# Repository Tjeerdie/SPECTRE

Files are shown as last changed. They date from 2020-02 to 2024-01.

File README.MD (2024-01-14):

# Project SPECTRE
Project SPECTRE	(Speeduino PrintEd Circuit board TjeeRdiE). This is a PCB with the hardware to run speeduino on a STM32F407VE6T board from ebay. (Or a STM32 BLACK_F407VE as it is sometimes called). 

Schematics and more information on the cpu board can be found here: (https://github.com/mcauser/BLACK_F407VE)

The case with connectors can be found here: https://nl.aliexpress.com/item/32839361268.html?spm=a2g0z.12010615.8148356.7.1da330edPBhz16

Latest tested version by author is 0.5.3. Version 0.5.4 is a cleaned up schematic plus a change to use resistor arrays rather than individual resistors by @vitorboss. The 0.5.4 version is not build and tested but functionally identical to 0.5.3. 

The design is provided as is. Just as it is stated in the license. The design is a hobby project and not specificly designed to adhere to any standard, so use it at your own risk.

A stand alone Peak and Hold injector driver board is now in a seperate repository. See: https://github.com/Tjeerdie/Peak-And-hold-Driver

## Getting Started
Take a look at the very informative manual for speeduino:
https://speeduino.com/Speeduino_manual.pdf

There is a difference for the TPS with respect to the manual. The TPS must be fed by 3.3V and not 5V like the other speeduino boards. For best performance it is better to wire all the grounds of the sensors to the GND pins and not use the PWR_GND or carchassis for this. 

How to load the firmware to the STM32 see:
https://speeduino.com/forum/viewtopic.php?f=13&t=1914&p=26572#p26572

## Board pinout

The TS Mapping column is the pin you enter in the "Local Auxillary Input Channel Configuration" when repurposing the input pins for another purpose (example: oil pressure sensor):
https://speeduino.com/forum/viewtopic.php?f=14&t=2809

| Pin# | Function | Alternative | Switch | Tuner Studio Mapping |
|-----|---|---|---|---|
| 1 | GND_PWR | | | |
| 2 | GND_PWR | | | |
| 3 | 12V_ECU | | | |
| 4 | 12V_ECU | | | |
| 5 | INJ_CH8 | | | 66 |
| 6 | INJ_CH7 | | | 67 |
| 7 | INJ_CH5 | | | 62 |
| 8 | INJ_CH6 | | | 64 |
| 9 | IDLE1-OUT | STEP_1A_OUT | JP5 | |
| 10  | BARO | | | A13 |
| 11  | Spare_2_out | Step_2B_OUT | JP6 | 71 |
| 12  | Spare_1_Out | Step_1B_OUT | JP7 | 72 |
| 13  | IGN_CH1 | | | |
| 14  | 02_2 | | | A4 |
| 15  | FAN | | | |
| 16  | IDLE2-OUT | STEP_2A_OUT | JP8 | |
| 17  | IAT | | | |
| 18  | IAT_2 | | | A0 |
| 19  | FUEL_PUMP | | | |
| 20  | CLT_2 | | | A1 |
| 21  | RS232_TX | | | |
| 22  | GND | IGN5-OUT | JP18 | |
| 23  | O2 | | | |
| 24  | INJ_CH4 | | | |
| 25  | MAP | | | |
| 26  | GND | IGN6-OUT | JP16 | |
| 27  | CLT | | | |
| 28  | INJ_CH3 | | | |
| 29  | CANH | | | |
| 30  | GND | | | |
| 31  | IGN_CH2 | | | |
| 32  | INJ_CH1 | | | |
| 33  | GND | | | |
| 34  | RS232_RX | | | |
| 35  | TPS | | | |
| 36  | IGN_CH3 | | |  24 |
| 37  | 5V | | | |
| 38  | FLEX_IN | | | |
| 39  | VR2- | | | |
| 40  | IGN_CH4 | | |  34 |
| 41  | VR2+ | | | |
| 42  | VR1- | | | |
| 43  | VR1+ | | | |
| 44  | INJ_CH2 | | | |
| 45  | CANL | | | |
| 46  | 3.3V | | | |
| 47  | BOOST-OUT | | | |
| 48  | TACHO-OUT | | | |

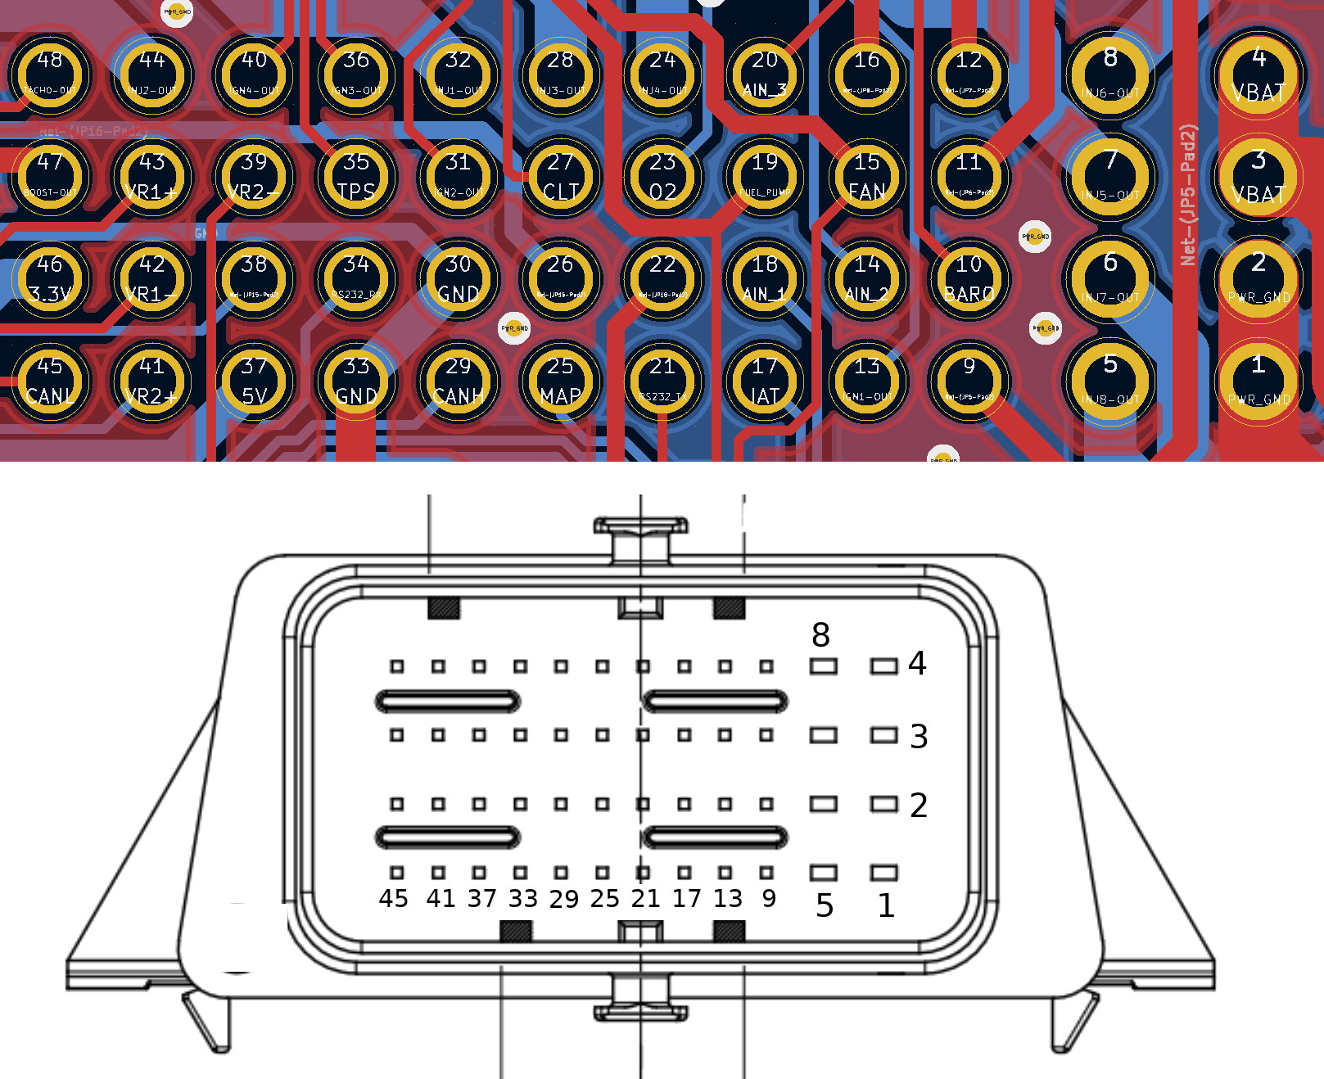
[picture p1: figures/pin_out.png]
connector pinout


## Jumper settings
There are 12 jumpers on the board to set/change various hardware configurations to suit your needs. with a sharp object scratch away the default bridge and use a solder bridge between the alternative configuration pins. The pull up resitors (JP1/JP4) are briged vs non bridged and no need to skratch anything away.
| JP# | Function | Default | Alternative|
|-----|---|---|---|
| 1 | Halleffect Pullup resistor| Not Conneced  | Connected  |
| 2 | Halleffect or VR input VR1| VR | Hall |
| 3 | Halleffect or VR input VR2| Hall | VR |
| 4 | Halleffect Pullup resistor| Not Conneced  | Connected  |
| 5 | STEP_1A_out or IDLE1-OUT  | IDLE1-OUT | STEP_1A_OUT|
| 6 | Spare_2_out or Step_2B_OUT| Spare_2_out | Step_2B_OUT|
| 7 | Spare_1_Out or Step_1B_OUT| Spare_1_Out | Step_1B_OUT|
| 8 | IDLE2-OUT or STEP_2A_OUT  | IDLE2-OUT | STEP_2A_OUT|
| 9  | Tacho out voltage		  | 12V output | 5V output |
| 10  | Ignition trigger out voltage		  | 5V output | 12V output |
| 15  | Flex fuel or Boot0 in | Flexfuel | Boot0 |
| 16  | Ignition 6 or GND | GND | IGN6 |
| 18  | Ignition 5 or GND _ | GND | IGN5 |

## Information for assembling a V0.5.X board
Information for board assembly and choosing components. If  you plan to build one of these it is important to note that a little electronic knowledge is very helpful if not essential to get the board working. The accompanying JLC bom list has most passive components in it, but not all components, some self assembly/soldering and part selection is required.  

### RS232 and bluetooth
The hardware serial port 1 is shared between bluetooth and RS232 output on the ECU connector. So that means you can only build it with the bluetooth module in place OR the max232 ic in place not both! That will break the communication. 

Dont forget to configure the bluetooth module to use 115200 bps baudrate using the HC-05/HC-06 AT commands. 

If you want your main/Tuner studio communiation to use the hardware serial port 1 (So bluetooth or RS232 on the ECU connector). Build the speeduino firmware in the arduino IDE with no "usb support" -> "None". In that case it will default to use hardware serial 1 as the communication.

If the bluetooth comms are not working and you are using a HC-05 or HC-06 module (both are 3.3v so its safe to direcly connect to the MCU). For V0.5.2 of SPECTRE [R37,R38] can be replaced by 0 ohms. For V0.5.3 [R38] can be replaced by 0 ohm. 

### Zener diodes
If you build the board with the injector driver mosfets to be BSP78 [Q10,Q11,Q13,Q14,Q18,Q19,Q20,Q21] you can leave the bzx84C39 + 1N4148 out [33,D34,D35,D36,D37,D38,D39,D40,D41,D42,D43,D44,D45,D46,D47,D48]. These are used for clamping, but the BSP78 has internal clamping. You can use other mosfets with SOT223 footprint in place of the BSP78. If these are not clamped or reptetative avalanch rated use the clamping diodes to keep them in spec.

### Vehicle Speed input
Note: This workaroud is no longer working. There is no solution yet.

Here is a description how to use one of the analog spare inputs (IAT_2 = ECU pin 18) as VSS input for speeduino. This can be a hall type sensor or a porximity sesnsor. it can NOT be a VR type sensor
1. Remove C2 and C4 from the board
2. On the MCU pin headers of the board connect PA0 to PA2 with a bit of solder
3. in Tuner Studio select pin 50 (PA2) for the VSS input pin.

PA0 (pin 48 in TS) can not work as VSS pin because of conflicting interrupts with the crank sensor (PE0)

## Tested on V0.5.2/V0.5.3
The following functions have been tested and confirmed to be working on a volvo B230FK redblock engine. This a 4 cylinder engine with small turbo. A VAG wasted spark coil with internal drivers is used as ignition<br/> 

VR2 input (Trigger 2) [OK]<br/> 
Halleffect trigger input (Trigger 1) [OK]<br/>
VR1 input (Trigger 1) [OK] <br/> 
Halleffect trigger input (Trigger 2) [OK]<br/>
Manifold Absolute pressure (MAP) [OK]<br/>
Injector outputs [OK]<br/>
Lambda sensor (O2) [OK]<br/>
Throttle position input [OK]<br/>
Bluetooth module (PA9,PA10) [OK]<br/>
Battery voltage reading [OK]<br/> 
Ignition outputs [OK]<br/> 
Fuel pump relay [OK]<br/>
FAN relay [OK]<br/>
PWM idle output [OK]<br/>
Coolant temperature (CLT) [OK]<br/>
Inlet Air Temperature (IAT) [OK]<br/>
RS232 TX [OK]<br/>
RS232 RX [OK]<br/>
BOOST output [OK]<br/>
Stepper idle output [OK]<br/> 
TACHO out [OK]<br/>

## To be tested on V0.5.2/V0.5.3
BARO <br/>
CAN bus TX<br/>
CAN bus RX<br/>
FLEX fuel input<br/>
Coolant temperature (CLT_2) <br/>
Inlet Air Temperature (IAT_2) <br/>
Lambda sensor (O2_2) <br/>

## License
This project is licensed under the GNU GENERAL PUBLIC LICENSE - see the [LICENSE.md](LICENSE.md) file for details

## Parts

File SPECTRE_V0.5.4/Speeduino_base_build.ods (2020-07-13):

Id | Designator | Package | Quantity | Designation | Supplier and ref
1 |  | R0603 | 26 | 10k | done for now
2 |  | R0603 | 22 | 1k | done for now
4 | R92,R91,R77,R76,R31 | R0603 | 5 | 1k8 | done for now
5 | R30 | R0603 | 5 | 2k49 | done for now
6 |  | R0603 | 1 | 0R0 | done for now
7 | U2 | TO-220-3_Vertical | 1 | LM78M05_TO220 | done for now
8 | D8 | D_MiniMELF_Handsoldering | 1 | Zener 5.1V | done for now
9 | D33,D32,D28,D27 | D_SMA | 10 | 1N4007 | done for now
11 | U6 | SOIC-16_4.55x10.3mm_P1.27mm | 1 | MAX3232 | done for now
12 | U5 | SO-8_5.3x6.2mm_P1.27mm | 1 | TJA1050
13 | U$1 | WIRELESS-BLUETOOTH-HC-05 | 1 | WIRELESS-BLUETOOTH-HC-05
14 | R97,R96,R79,R78 | R0603 | 15 | 470R | done for now
15 | U3 | SOT-23 | 1 | TL431DBZ | done for now
16 |  | R0603 | 1 | 120R | done for now
18 | Q26,Q25,Q13,Q12 | SOT223 | 11 | BSP78 | done for now
19 | Q22,Q21,Q10,Q11 | SOT-23_Handsoldering | 4 | AO3401A | done for now
20 | Q17,Q16,Q9,Q8 | SOT-23_Handsoldering | 4 | AO3422 | done for now
21 | J2 | PinHeader_2x04_P2.54mm_Vertical | 1 | Conn_02x04_Odd_Even
22 | F2 | R_1812_4532Metric_Pad1.30x3.40mm_HandSolder | 2 | PPTC 16V2A | done for now
23 | J1 | PinHeader_1x06_P2.54mm_Vertical | 1 | Conn_01x06_Male | done for now
24 | U4 | Molex_48 | 1 | molex_48pin | done for now
25 | JP12,JP9 | 2X24 | 2 | PINHD-2X24 | done for now
26 |  | C0603 | 14 | 100nf | done for now
27 |  | C0603 | 12 | 220nf | done for now
28 |  | C0603 | 2 | 1nf | done for now
29 |  | SOT23 | 16 | BAT54S | done for now
30 |  | D_MiniMELF_Handsoldering | 1 | Zener 3.6V | done for now
31 | U1 | 21-0055H_16 | 1 | MAX9926UAEE+
32 | A1 | Pololu_Breakout-16_15.2x20.3mm | 1 | Pololu_Breakout_DRV8825
33 |  | R0603 | 10 | 100R | done for now
34 | R2 | RV_Disc_D12mm_W3.9mm_P7.5mm | 1 | VARISTOR-18V | done for now
35 | R72 | R0603 | 1 | 5470R | done for now
36 | R71 | R0603 | 1 | 100R | done for now
37 | R70 | R0603 | 1 | 220R | done for now
38 |  | LED-0603 | 5 | YEL | done for now
39 | JP11,JP10 | PinHeader_1x02_P2.54mm_Vertical | 2 | Jumper_NO_Small | done for now
40 |  | R0603 | 1 | 5k1 | done for now
41 |  | R0603 | 1 | 33k | done for now
43 |  | R0603 | 4 | 4k7 | done for now
44 |  | R0603 | 4 | 9k1 | done for now
45 | JP4,JP1 | SolderJumper-2_P1.3mm_Open_Pad1.0x1.5mm | 2 | Jumper_NO_Small | done for now
47 |  | C1206 | 2 | 10uf | done for now
48 | Q2,Q5, | SOT-23 | 7 | AO3400

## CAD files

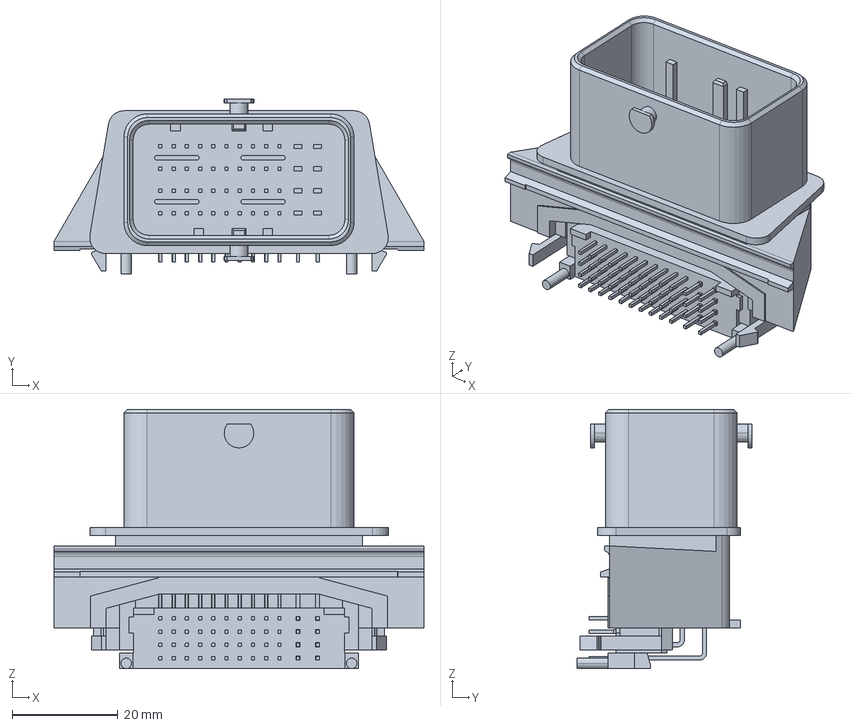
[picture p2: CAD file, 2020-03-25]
SPECTRE_V0.5.4/5007620481.stp
69.9 x 33.2 x 49.0 mm

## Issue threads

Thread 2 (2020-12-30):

BOM file is not complete

pkagiantas, 2020-12-30:
some of the parts have no designation like like the 26 10K resistors etc

Tjeerdie, 2020-12-30:
Ah thanks! fixed it. I used it myself to build the board en removed all numbers already placed on the board. Now i repopulated it again with the latest full BOM.

pkagiantas, 2020-12-30:
cool i ended up finding everything from the eeschema some parts are wrong labeled from the v5.2 schematics

Tjeerdie, 2020-12-30:
you can easily export the same style BOM from kicad. No need to find them by hand!

pkagiantas, 2020-12-30:
thanks ill give it a go

one more question i did got some v5 by mistake do those work ok should i make them or not bother with them ?

Tjeerdie, 2020-12-30:
I have 3 V0.5.2 bare/unpopulated boards here still. I had my engine running on a V0.5.1 and there is another 6 cylinder engine out there that runs an adapted V0.5.1. But i would start with the V0.5.2 that one is the latest the other designs are just put online for reference.

pkagiantas, 2020-12-30:
yeah i received them today 5 of the v5.2 and 5 of the v5 ( by mistake ) i started on V5.2 to test on a bike engine but i was asking if i should keep the v5 or throw them away

Tjeerdie, 2020-12-30:
ah now i understand. The V0.5.0 should work i think... I see some resistor values need tweaking to the new value (like for crank and cam). But in general it could work. but no guarantee.

pkagiantas, 2020-12-30:
cool no wories ! more project to fiddle with ;P

Closed 2020-12-30.

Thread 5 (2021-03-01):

Q12/Q6 Function ?

pkagiantas, 2021-03-01:
hey hi im making my second one 5.2 !

what are the Q12 and Q6 for ? ( PA6 PE6 )

im making it for a 4 cyl wasted spark batch fire engine so im populating just the circuits i need only

Tjeerdie, 2021-03-01:
Q12 is visual feedback that the board is running (PA6 is same pin as the onboard led) so not strictly necessary
Q6 is for the cooling FAN relay. If you want the radiator cooling fan controlled from the speeduino

pkagiantas, 2021-03-01:
cool so board will run with both of those circuits unpopulated correct ?

also i haven't seen a clutch input have you made it or i am just that blind ? :P

Tjeerdie, 2021-03-02:
You would loose aforementioned functionality, nothing else. You could use one of the unused inputs (analog) for clutch.

pkagiantas, 2021-03-02:
so for the clutch do i need to use a darlington array like the 0.4.3 boards or the bard can handle it
and witch pins are unused and analog on the stm ?

sorry for so many questions but i haven't use that board at all

Tjeerdie, 2021-03-03:
For example use AIN_3 for this, if the board is build correctly it should be 15 Volt safe. (never tested so on your own risk). The best way is to remove R57, Make R61 1k. But that is not strictly necessary.  Make sure the bat53s is in place!
ECU pin 20 as input
MCU input PA1 that has number 49 (so use 49 in Tuner Studio).

pkagiantas, 2021-03-03:
thanks im gonna try your way :) 👍

Closed 2021-03-10.

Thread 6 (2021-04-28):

Sd datalog

pkagiantas, 2021-04-28:
im facing a strange issue with the sd card datalog
and i cant seem to make it work

some times it starts logging fine and others i get the sd er and it wont work

have you faced the same issue before ? do you need any more info or tests ?

Tjeerdie, 2021-04-28:
Ah sdcard logging is not SPECTRE specifically ;-). Couple of questions:
- Is the sdcard formatted FAT16 or FAT32?
- Is a file created on the sdcard or no file is created at all?
- Do not install de STM32SD library, that one does that type of errors and more. The corrected library is included in the PR.

pkagiantas, 2021-04-28:
i have to check on the library i cant remember which one i have
the card is fat32 the file is there some times 0kb size tho

pkagiantas, 2021-04-28:
STM32RTC is the library  i use

Tjeerdie, 2021-04-28:
> STM32RTC is the library i use

That's correct. Did you set the RTC time correct? And is the file created with correct time and date?

pkagiantas, 2021-04-28:
yeah files are created with the correct time stamp as a name
it inconsistent when it will work or not
for example today i started the bike 10 times and i got 5-6 files with partial logs some times it runs ok sometimes it starts logging and then stops and sometime it will start with the sd er from the getgo

Tjeerdie, 2021-04-28:
Hmm i had similar issues when i started the Sdcard project. Issues where related to other interrupts running and interrupting Sdcard writes. That stopped the logging at random. But that shouldn't be the case anymore.

I assume you tried various sd-cards? I never had a issue with any. When i have time next week ok so i wil try a fresh install and see if it happens to me too.

pkagiantas, 2021-04-28:
yeah i have tried three sd cards two are the same brand 8gb and one is a 64g that is not working at all :P

Tjeerdie, 2021-04-28:
Welll I updated that without checking with a longer log if Sdcard logging still works as expected. Short still worked. If you open a version of couple of weeks back without newest master merged in maybe it changes something. But should still just work. I will try next week when i hopefully have some time.

pkagiantas, 2021-04-28:
no worries ill try to find an older version to test :D

Closed 2022-07-11.

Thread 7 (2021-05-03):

[Question] Regarding the PPTC fuses

Griletos, 2021-05-03:
I'm having a hard time finding PPTC's with the same 16v2a ratings the project requires here in my country.
Closest ones I was able to find are 16v1.5a and 30v2.5a.
Just wanted to know if one of those are suitable, or if I can use standard 2a fuses, or should I really stick to the 16v2a PPTC, in which case I'll import a few.

Tjeerdie, 2021-05-03:
the 1.5A would be fine. The 2A is just what i had lying around here.
1. The 5 volt regulator only takes maximum 1A continuous so a 1A fuse would be more than enough. 1A is not even possible without cooling the regulator.
2. The stepper driver should also not be much more than 1A continuous but i never tested.

Griletos, 2021-05-03:
Thank you very much, I don't plan on using the stepper driver, so it won't actually pose a problem.

Closed 2021-05-03.

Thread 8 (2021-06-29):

Eagle PCB

TadyTheFish, 2021-06-29:
Could you provide sch and brd files for Eagle PCB?
Thank you

Tjeerdie, 2021-06-30:
Its designed the board using Kicad so i do not have a eagle project anymore.

TadyTheFish, 2021-06-30:
Ok thank you

Closed 2021-06-30.

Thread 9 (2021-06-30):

Clutch switch input

andredalmolin, 2021-06-30:
Hi!
I'm just finishing the wiring for an Spectre to use in an VW Jetta 2.5 5cyl with turbo.
We wish to use flat shift, but I didnt find an clutch input. There is any unused input that I can reassign to clutch input?

Tjeerdie, 2023-07-02:
Sorry for the late response, but maybe someone else can still sue this

You could try use the flex fuel input pin, if you do not have a flex fuel sensor connected

Closed 2023-07-02.

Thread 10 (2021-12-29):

Some info is not correct

pkagiantas, 2021-12-29:
Baro is working when set to pin Α13 on Tuner Studio not on A9

JP15 ( Flex fuel or Boot0 ) does not existing in V5.2

Halleffect or VR input VR1 default on V5.2 is on HALL not on VR

on the Jumper section you have (  Ignition 6 or GND ) for the IGN7

thats what i have found so far it might help someone
your master is working fine on my engine ( kawasaki z1000 )
( cant get a good cam signal to run sequential but i think that is not related to the board )

the only thinks missing is the datalogging on the sd ( its a must for a bike if you want to road tune it )
quick shifter would be nice too but cant get it all :P

also what is the latest board version 5.2 or 5.3 or 5.4 ?

Tjeerdie, 2023-07-02:
Thanks! I checked all of them and changed most of them in the readme

Except the VR1 being default to VR, because that is actually the case. (I use the VR sensor and the jumper is in the default setting)

Closed 2023-07-02.

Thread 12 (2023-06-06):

Can I Use A Diffrent Stepper Driver?

CaptionAdam, 2023-06-06:
Title Explains it quite nicely

Tjeerdie, 2023-07-02:
If its pin compatible with the current stepper drive i would´t see why not.

These are a few different boards with the same pinout.

google for:
A4988 Stepper Motor Driver Carrier Board alternatives

Closed 2023-07-02.

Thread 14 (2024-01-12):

Partly assembled PCB

anyoneeee, 2024-01-12:
Hi, I´m not really into electronics, but I gave it a try and ordered some PCB from PCBWay. They partly assembled the board. Now I see that all the mosfets weren´t in the BOM I found (it´s V0.5.3 btw). At Q10 is not very much space to D37. Do I need D37? What is D37? Where do I find a complete BOM? Do you have pictures of your board? I can´t find any pictures from people that have built the board. So many questions...
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

Tjeerdie, 2024-01-14:
Hi anyoneeee

First of all i will add to the read-me that it might be a good idea to be familiar with electronics before building this board. It all works if build with according to the schematics. But you might need to fiddle a bit to get some things working. For your specific application.  Also soldering parts yourself is required.

I will add to the read-me that the jlc-pcb bom list is not complete, mostly because they do not have all the parts in their inventory.  And also assembly on the bottom side is not supported by JLC pcb. And no thu-hole components are assembled by JLC. I am actually surprised the BOM list still worked! Because usually parts are added/removed from the inventory list on a regular basis. The full BOM list could easily be generated from Kicad using the schematic

The BSP78 I used is also hard to come by now days. So a IRFL024N is a non protected mosfet that i used as a alternative. But it has no protection so it is easier to blow one up when somethings are connected wrong.

I will add some pictures of one of my boards assembled to the point that I could use it.

anyoneeee, 2024-01-14:
Hi Tjeerdie, thank you for the quick answer. Knowing how to use KiCad a little bit helps too and reading the description also 😄 . I ordered the BSP78, very cool MOSFET. I didn´t know they could have a short circuit protection in that little thing. Pictures of your assembled boards would be very helpful for me. Did you already use the board on other engines than the 4 cylinder in the description? Thank you for your support.

From your description:
Zener diodes
If you build the board with the injector driver mosfets to be BSP78 [Q10,Q11,Q13,Q14,Q18,Q19,Q20,Q21] you can leave the bzx84C39 + 1N4148 out [33,D34,D35,D36,D37,D38,D39,D40,D41,D42,D43,D44,D45,D46,D47,D48]. These are used for clamping, but the BSP78 has internal clamping. You can use other mosfets with SOT223 footprint in place of the BSP78. If these are not clamped or reptetative avalanch rated use the clamping diodes to keep them in spec.

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

#,"Reference","Qty","Value","Footprint","DNP"
--
1,"A1","1","Pololu_Breakout_DRV8825","Module:Pololu_Breakout-16_15.2x20.3mm",""
2,"C1, C2, C9, C10, C13, C19, C21,   C22, C25, C26, C29, C30, C31,   C32","14","100nf","Speeduino_base:C0603",""
3,"C3, C4, C8, C11, C14, C16, C17,   C20, C23, C24, C27,   C28","12","220nf","Speeduino_base:C0603",""
4,"C5,   C7","2","1nf","Speeduino_base:C0603",""
5,"C6,   C15","2","10uf","Speeduino_base:C1206",""
6,"C12,   C18","2","470uF   6.3V","Capacitor_SMD:CP_Elec_6.3x7.7",""
7,"D1, D2, D3, D5, D7, D9, D10, D11,   D12, D15, D16, D17, D19, D21, D22,   D24","16","BAT54S","Speeduino_base:SOT23",""
8,"D4, D14, D20, D30, D31,   D32","6","1N4007","Diode_SMD:D_SMA",""
9,"D6","1","Zener   3.6V","Diode_SMD:D_MiniMELF_Handsoldering",""
10,"D8","1","Zener   5.1V","Diode_SMD:D_MiniMELF_Handsoldering",""
11,"D13, D18, D26, D27, D28,   D29","6","YEL","Speeduino_base:LED-0603",""
12,"D33, D35, D36, D39, D40, D43,   D44,   D45","8","1N4148WS","Diode_SMD:D_SOD-323",""
13,"D34, D37, D38, D41, D42, D46,   D47,   D48","8","BZX84C39","Diode_SMD:D_SOT-23_ANK",""
14,"F1,   F2","2","PPTC   16V2A","Resistor_SMD:R_1812_4532Metric_Pad1.30x3.40mm_HandSolder",""
15,"J1","1","Conn_01x06_Male","Connector_PinHeader_2.54mm:PinHeader_1x06_P2.54mm_Vertical",""
16,"J2","1","Conn_02x04_Odd_Even","Speeduino_base:PinHeader_2x04_P2.54mm_Vertical",""
17,"J3","1","ProtoArea","Speeduino_base:Proto_area",""
18,"JP1,   JP4","2","Jumper_NO_Small","Jumper:SolderJumper-2_P1.3mm_Open_Pad1.0x1.5mm",""
19,"JP2, JP3, JP5, JP6, JP7, JP8,   JP9, JP10, JP15, JP16,   JP18","11","SolderJumper_3_Bridged12","Jumper:SolderJumper-3_P1.3mm_Bridged12_Pad1.0x1.5mm",""
20,"JP11,   JP12","2","PINHD-2X24","Speeduino_base:2X24",""
21,"JP13","1","Jumper_NC_Small","Jumper:SolderJumper-2_P1.3mm_Bridged_Pad1.0x1.5mm",""
22,"JP14","1","Jumper_NO_Small","Connector_PinHeader_2.54mm:PinHeader_1x02_P2.54mm_Vertical",""
23,"Q1, Q6, Q7,   Q12","4","AO3400","Speeduino_base:SOT-23",""
24,"Q10, Q11, Q13, Q14, Q15, Q16,   Q17, Q18, Q19, Q20,   Q21","11","BSP78","Speeduino_base:SOT223",""
25,"R1, R22, R31, R42,   R57","5","2k49","Speeduino_base:R0603",""
26,"R2","1","VARISTOR-18V","Varistor:RV_Disc_D12mm_W3.9mm_P7.5mm",""
27,"R3, R12, R15, R21, R32, R35,   R65, R68,   R69","9","1k","Speeduino_base:R0603",""
28,"R4, R6, R8, R18, R23, R24, R27,   R33, R37, R41, R49, R50, R55, R60, R61, R64,   R77","17","470R","Speeduino_base:R0603",""
29,"R5, R11, R13, R14, R16, R19,   R36, R59, R66, R79, R80, R81, R82, R86, R87, R88, R89, R90, R91,   R92","20","10k","Speeduino_base:R0603",""
30,"R7, R17, R38, R58, R62, R63,   R70,   R71","8","10R","Resistor_SMD:R_0603_1608Metric_Pad1.05x0.95mm_HandSolder",""
31,"R9, R25, R28,   R46","4","4k7","Speeduino_base:R0603",""
32,"R10, R26, R29,   R47","4","9k1","Speeduino_base:R0603",""
33,"R20","1","0R0","Speeduino_base:R0603",""
34,"R30","1","1k8","Speeduino_base:R0603",""
35,"R34, R39, R40, R43, R48, R51,   R52, R53, R54, R56, R67, R76, R78, R83, R84,   R85","16","100R","Speeduino_base:R0603",""
36,"R44","1","33k","Speeduino_base:R0603",""
37,"R45","1","5k1","Speeduino_base:R0603",""
38,"R74","1","120R","Speeduino_base:R0603",""
39,"R75","1","220R","Speeduino_base:R0603",""
40,"U1","1","MAX9926UAEE+","Speeduino_base:21-0055H_16",""
41,"U2","1","LM78M05_TO220","Package_TO_SOT_THT:TO-220-3_Horizontal_TabUp",""
42,"U3","1","TL431DBZ","Package_TO_SOT_SMD:SOT-23",""
43,"U4","1","molex_48pin","Speeduino_base:Molex_48",""
44,"U5","1","TJA1050","Package_SO:SO-8_5.3x6.2mm_P1.27mm",""
45,"U6","1","MAX3232","Package_SO:SOIC-16_4.55x10.3mm_P1.27mm",""
46,"U7, U8, U9,   U10","4","MIC4427","Package_SO:SO-8_3.9x4.9mm_P1.27mm",""
47,"U$1","1","WIRELESS-BLUETOOTH-HC-05","Speeduino_base:WIRELESS-BLUETOOTH-HC-05",""

anyoneeee, 2024-01-19:
Assembled most of the parts today. Only the HC-05 Bluetooth module and the MAX9926UAEE+ VR Sensor Interface are missing.

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

Closed 2024-01-21.

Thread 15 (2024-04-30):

Which branch/fork to use yours or Vitors?

ruckusman, 2024-04-30:
Not really an issue but probably the best way to contact you - I've located Vitor's fork and noticed that he has made some recent commits to his.

https://github.com/VitorBoss/SPECTRE

Would it be preferable to use his fork to get PCB's fabricated?

Awesome board by the way, I don't understand why it hasn't received much more attention - the feature set is excellent or 4 cylider dual injector builds.

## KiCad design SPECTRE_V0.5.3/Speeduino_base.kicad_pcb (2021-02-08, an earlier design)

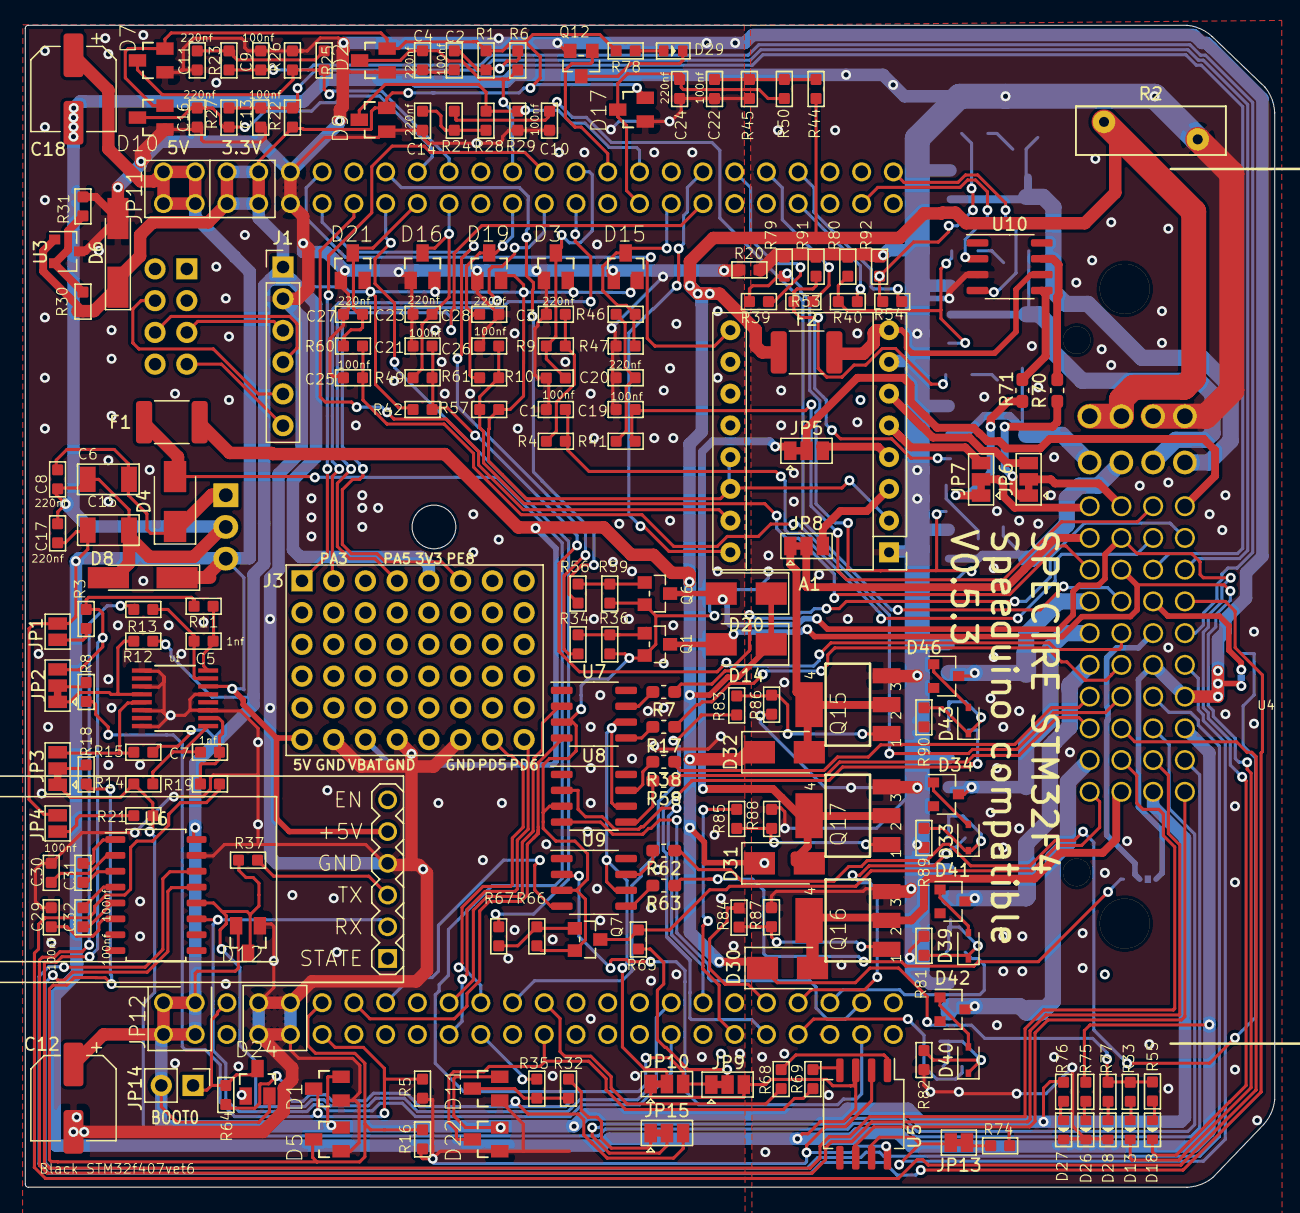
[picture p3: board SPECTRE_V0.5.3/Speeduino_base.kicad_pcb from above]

Board: 2 copper layers, 100.0 x 93.0 mm, 217 parts (0 on the bottom side), 180 nets.

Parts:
A1: Pololu_Breakout_DRV8825; Pololu_Breakout-16_15.2x20.3mm
C1, C2, C9, C10, C13, C19, C21, C22, C25, C26, C29, C30, C31, C32: 100nf; C0603
C3, C4, C8, C11, C14, C16, C17, C20, C23, C24, C27, C28: 220nf; C0603
C5, C7: 1nf; C0603
C6, C15: 10uf; C1206
C12, C18: 470uF 6.3V; CP_Elec_6.3x7.7
D1, D2, D3, D5, D7, D9, D10, D11, D12, D15, D16, D17, D19, D21, D22, D24: BAT54S; SOT23
D4, D14, D20, D30, D31, D32: 1N4007; D_SMA
D6: Zener 3.6V; D_MiniMELF_Handsoldering
D8: Zener 5.1V; D_MiniMELF_Handsoldering
D13, D18, D26, D27, D28, D29: YEL; LED-0603
D33, D35, D36, D39, D40, D43, D44, D45: 1N4148WS; D_SOD-323
D34, D37, D38, D41, D42, D46, D47, D48: BZX84C39; D_SOT-23_ANK
F1, F2: PPTC 16V2A; R_1812_4532Metric_Pad1.30x3.40mm_HandSolder
J1: Conn_01x06_Male; PinHeader_1x06_P2.54mm_Vertical
J2: Conn_02x04_Odd_Even; PinHeader_2x04_P2.54mm_Vertical
J3: ProtoArea; Proto_area
JP1, JP4: Jumper_NO_Small; SolderJumper-2_P1.3mm_Open_Pad1.0x1.5mm
JP2, JP3, JP5, JP6, JP7, JP8, JP9, JP10, JP15, JP16, JP18: SolderJumper_3_Bridged12; SolderJumper-3_P1.3mm_Bridged12_Pad1.0x1.5mm
JP11, JP12: PINHD-2X24; 2X24
JP13: Jumper_NC_Small; SolderJumper-2_P1.3mm_Bridged_Pad1.0x1.5mm
JP14: Jumper_NO_Small; PinHeader_1x02_P2.54mm_Vertical
Q1, Q6, Q7, Q12: AO3400; SOT-23
Q10, Q11, Q13, Q14, Q15, Q16, Q17, Q18, Q19, Q20, Q21: BSP78; SOT223
R1, R22, R31, R42, R57: 2k49; R0603
R2: VARISTOR-18V; RV_Disc_D12mm_W3.9mm_P7.5mm
R3, R12, R15, R21, R32, R35, R65, R68, R69: 1k; R0603
R4, R6, R8, R18, R23, R24, R27, R33, R37, R41, R49, R50, R55, R60, R61, R64, R77: 470R; R0603
R5, R11, R13, R14, R16, R19, R36, R59, R66, R79, R80, R81, R82, R86, R87, R88, R89, R90, R91, R92: 10k; R0603
R7, R17, R38, R58, R62, R63, R70, R71: 10R; R_0603_1608Metric_Pad1.05x0.95mm_HandSolder
R9, R25, R28, R46: 4k7; R0603
R10, R26, R29, R47: 9k1; R0603
R20: 0R0; R0603
R30: 1k8; R0603
R34, R39, R40, R43, R48, R51, R52, R53, R54, R56, R67, R76, R78, R83, R84, R85: 100R; R0603
R44: 33k; R0603
R45: 5k1; R0603
R74: 120R; R0603
R75: 220R; R0603
U1: MAX9926UAEE+; 21-0055H_16
U2: LM78M05_TO220; TO-220-3_Horizontal_TabUp
U3: TL431DBZ; SOT-23
U4: molex_48pin; Molex_48
U5: TJA1050; SO-8_5.3x6.2mm_P1.27mm
U6: MAX3232; SOIC-16_4.55x10.3mm_P1.27mm
U7, U8, U9, U10: MIC4427; SO-8_3.9x4.9mm_P1.27mm
U$1: WIRELESS-BLUETOOTH-HC-05

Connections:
3.3V: A1.2, A1.13, A1.14, C12.1, D1.2, D2.2, D3.2, D5.2, D6.1, D7.2, D9.2, D10.2, D11.2, D12.2, D15.2, D16.2, D17.2, D19.2, D21.2, D22.2, D24.2, J1.1, J3.5, JP11.5, JP11.6, JP11.7, JP11.8, JP12.1, JP12.2, JP12.3, JP12.4, JP14.2, R1.2, R12.2, R15.2, R22.2, R30.1, R42.2, R57.2, R76.2, R78.2, U3.1, U4.46, U6.16
5V: C15.2, C17.2, C18.1, D8.1, J3.41, JP1.2, JP4.2, JP9.3, JP10.1, JP11.1, JP11.2, JP11.3, JP11.4, R75.2, U1.14, U2.3, U4.37, U5.3, U$1.5
/BT_TX: R37.2, U$1.3
AIN_1: C2.2, R1.1, R6.1, U4.18
AIN_2: C1.2, R4.1, U4.14
AIN_3: C26.2, R57.1, R61.1, U4.20
BARO: C19.2, R41.1, U4.10
BME280_CS: J1.5, J2.4
BOOST-OUT: D30.2, Q16.2, Q16.4, U4.47
BOOT0: D24.3, JP12.5, JP14.1, R64.1
BOOT0_EXT: JP15.3, R64.2
CANH: JP13.2, U4.29, U5.7
CANL: R74.2, U4.45, U5.6
CLT: C21.2, R42.1, R49.1, U4.27
FAN: D18.-, D20.2, Q6.3, U4.15
FLEX_FUEL_IN: JP15.1, R32.2
FUEL_PUMP: D13.-, D14.2, Q1.3, U4.19
GND: C1.1, C2.1, C3.1, C4.1, C9.1, C10.1, C11.1, C12.2, C13.1, C14.1, C16.1, C19.1, C20.1, C21.1, C22.1, C23.1, C24.1, C25.1, C26.1, C27.1, C28.1, C29.2, C30.2, D1.1, D2.1, D3.1, D5.1, D6.2, D7.1, D9.1, D10.1, D11.1, D12.1, D15.1, D16.1, D17.1, D19.1, D21.1, D22.1, D24.1, J1.2, J3.42, J3.44, J3.46, JP11.9, JP11.10, JP12.7, JP12.8, JP12.9, JP12.10, JP16.1, JP18.1, Q12.2, R5.2, R10.1, R16.2, R20.1, R26.1, R29.1, R31.2, R45.1, R47.1, U1.1, U1.3, U1.6, U1.8, U1.11, U1.13, U3.3, U4.30, U4.33, U5.2, U5.8, U6.15, U$1.4
IAT: C13.2, R22.1, R27.1, U4.17
IDLE1-OUT: D31.2, JP5.1, Q17.2, Q17.4
IDLE2-OUT: D32.2, JP8.1, Q15.2, Q15.4
IGN1-OUT: R7.1, U4.13
IGN2-OUT: R17.1, U4.31
IGN3-OUT: R38.1, U4.36
IGN4-OUT: R58.1, U4.40
IGN5-OUT: JP18.3, R62.1
IGN6-OUT: JP16.3, R63.1
INJ1-OUT: D41.1, Q13.2, Q13.4, U4.32
INJ2-OUT: D42.1, Q14.2, Q14.4, U4.44
INJ3-OUT: D34.1, Q18.2, Q18.4, U4.28
INJ4-OUT: D46.1, Q19.2, Q19.4, U4.24
INJ5-OUT: D37.1, Q10.2, Q10.4, U4.7
INJ6-OUT: D47.1, Q20.2, Q20.4, U4.8
INJ7-OUT: D38.1, Q11.2, Q11.4, U4.6
INJ8-OUT: D48.1, Q21.2, Q21.4, U4.5
MAP: C9.2, R23.1, U4.25
unnamed: C3.2, R4.2, R9.1
unnamed: C5.1, R13.2, U1.15
unnamed: C5.2, R11.2, U1.16
unnamed: C6.2, C8.2, D4.1, U2.1
unnamed: C7.1, R19.2, U1.10
unnamed: C7.2, R14.2, U1.9
unnamed: C11.2, R23.2, R25.1
unnamed: C14.2, R24.2, R28.1
unnamed: C20.2, R41.2, R46.1
unnamed: C22.2, R44.1, R45.2, R50.1
unnamed: C29.1, U6.6
unnamed: C30.1, U6.2
unnamed: C31.1, U6.1
unnamed: C31.2, U6.3
unnamed: C32.1, U6.4
unnamed: C32.2, U6.5
unnamed: D11.3, R32.1, R35.2
unnamed: D13.+, R33.1
unnamed: D18.+, R55.1
unnamed: D26.+, R75.1
unnamed: D27.+, R76.1
unnamed: D28.+, R77.1
unnamed: D29.+, R78.1
unnamed: D29.-, Q12.3
unnamed: D33.1, Q18.1, R52.1, R89.1
unnamed: D33.2, D34.2
unnamed: D35.1, Q10.1, R39.1, R79.1
unnamed: D35.2, D37.2
unnamed: D36.1, Q11.1, R40.1, R80.1
unnamed: D36.2, D38.2
unnamed: D39.1, Q13.1, R43.1, R81.1
unnamed: D39.2, D41.2
unnamed: D40.1, Q14.1, R48.1, R82.1
unnamed: D40.2, D42.2
unnamed: D43.1, Q19.1, R51.1, R90.1
unnamed: D43.2, D46.2
unnamed: D44.1, Q20.1, R53.1, R91.1
unnamed: D44.2, D47.2
unnamed: D45.1, Q21.1, R54.1, R92.1
unnamed: D45.2, D48.2
unnamed: JP1.1, R3.2
unnamed: JP2.1, R12.1, U1.4
unnamed: JP2.2, R8.2
unnamed: JP3.2, R18.2
unnamed: JP3.3, R15.1, U1.5
unnamed: JP4.1, R21.2
unnamed: JP5.2, U4.9
unnamed: JP6.2, U4.11
unnamed: JP7.2, U4.12
unnamed: JP8.2, U4.16
unnamed: JP9.2, R65.2
unnamed: JP10.2, U7.6, U8.6, U9.6
unnamed: JP13.1, R74.1
unnamed: JP15.2, U4.38
unnamed: JP16.2, U4.26
unnamed: JP18.2, U4.22
unnamed: Q1.1, R34.2, R36.1
unnamed: Q6.1, R56.2, R59.1
unnamed: Q7.1, R66.2, R67.2
unnamed: Q15.1, R83.2, R86.2
unnamed: Q16.1, R84.2, R87.2
unnamed: Q17.1, R85.2, R88.2
unnamed: R7.2, U7.7
unnamed: R17.2, U7.5
unnamed: R30.2, R31.1, U3.2
unnamed: R38.2, U8.7
unnamed: R58.2, U8.5
unnamed: R62.2, U9.7
unnamed: R63.2, U9.5
unnamed: R68.2, U5.1
unnamed: R69.2, U5.4
unnamed: R70.2, U10.7
unnamed: R71.2, U10.5
O2: C10.2, R24.1, U4.23
PA0: C4.2, D2.3, JP11.23, R6.2
PA1: C28.2, D19.3, JP11.24, R61.2
PA2: J3.1, JP11.25
PA3: J3.2, JP11.26
PA4: D3.3, JP11.27, R9.2, R10.2
PA5: J3.4, JP11.28
PA6: JP11.29, Q12.1
PA8: JP12.35, U8.2
PA9: JP12.34, U6.11, U$1.2
PA10: D12.3, JP12.33, R37.1, U6.12
PB1: D15.3, JP11.34, R46.2, R47.2
PB7: JP12.15, U9.4
PB9: JP12.13, U7.4
PB12: JP11.46, U10.2
PB13: JP11.47, U10.4
PC0: C16.2, D10.3, JP11.17, R27.2
PC1: C27.2, D21.3, JP11.18, R60.2
PC2: D7.3, JP11.19, R25.2, R26.2
PC3: C23.2, D16.3, JP11.20, R49.2
PC4: D9.3, JP11.31, R28.2, R29.2
PC5: C24.2, D17.3, JP11.32, R50.2
PC6: JP12.39, R84.1
PC7: JP12.38, R85.1
PC13: JP11.16, R67.1
PD0: D22.3, JP12.26, R69.1
PD1: JP12.25, R68.1
PD3: JP12.23, R83.1
PD4: JP12.22, R35.1
PD5: J3.47, JP12.21
PD6: J3.48, JP12.20
PD7: JP12.19, U7.2
PD9: JP12.46, U9.2
PD10: JP12.45, U8.4
PD12: JP12.43, R43.2
PD13: JP12.42, R48.2
PD14: JP12.41, R52.2
PD15: JP12.40, R51.2
PE0: D1.3, JP12.12, R5.1, R8.1
PE1: D5.3, JP12.11, R16.1, R18.1
PE2: A1.9, JP11.11
PE3: JP11.12, R34.1
PE5: A1.15, JP11.14
PE6: JP11.15, R56.1
PE7: A1.16, JP11.35
PE8: J3.6, JP11.36
PE9: JP11.37, R39.2
PE11: JP11.39, R53.2
PE13: JP11.41, R54.2
PE14: JP11.42, R40.2
PWR_GND: A1.1, A1.7, C6.1, C8.1, C15.1, C17.1, C18.2, D8.2, D26.-, D27.-, D28.-, Q1.2, Q6.2, Q7.2, Q10.3, Q11.3, Q13.3, Q14.3, Q15.3, Q16.3, Q17.3, Q18.3, Q19.3, Q20.3, Q21.3, R2.1, R20.2, R36.2, R59.2, R66.1, R79.2, R80.2, R81.2, R82.2, R86.1, R87.1, R88.1, R89.2, R90.2, R91.2, R92.2, U2.2, U4.1, U4.2, U7.3, U8.3, U9.3, U10.3
RS232_RX: U4.34, U6.13
RS232_TX: U4.21, U6.14
SPI1_MISO: J1.6, J2.7
SPI1_MOSI: J1.4, J2.6
SPI1_SCK: J1.3, J2.5
STEP_1A_OUT: A1.4, JP5.3
STEP_1B_OUT: A1.5, JP7.3
STEP_2A_OUT: A1.3, JP8.3
STEP_2B_OUT: A1.6, JP6.3
Spare_1-Out: JP7.1, R71.1
Spare_2-Out: JP6.1, R70.1
TACHO-OUT: Q7.3, R65.1, U4.48
TPS: C25.2, R60.1, U4.35
VBAT: D14.1, D20.1, D30.1, D31.1, D32.1, F1.1, F2.1, J3.43, R2.2, R33.2, R44.2, R55.2, R77.2, U4.3, U4.4
VBAT_F1: D4.2, F1.2, JP9.1, JP10.3
VR1+: JP2.3, R3.1, R11.1, U4.43
VR1-: R13.1, U4.42
VR2+: JP3.1, R14.1, R21.1, U4.41
VR2-: R19.1, U4.39
V_IDLE: A1.8, F2.2, U10.6

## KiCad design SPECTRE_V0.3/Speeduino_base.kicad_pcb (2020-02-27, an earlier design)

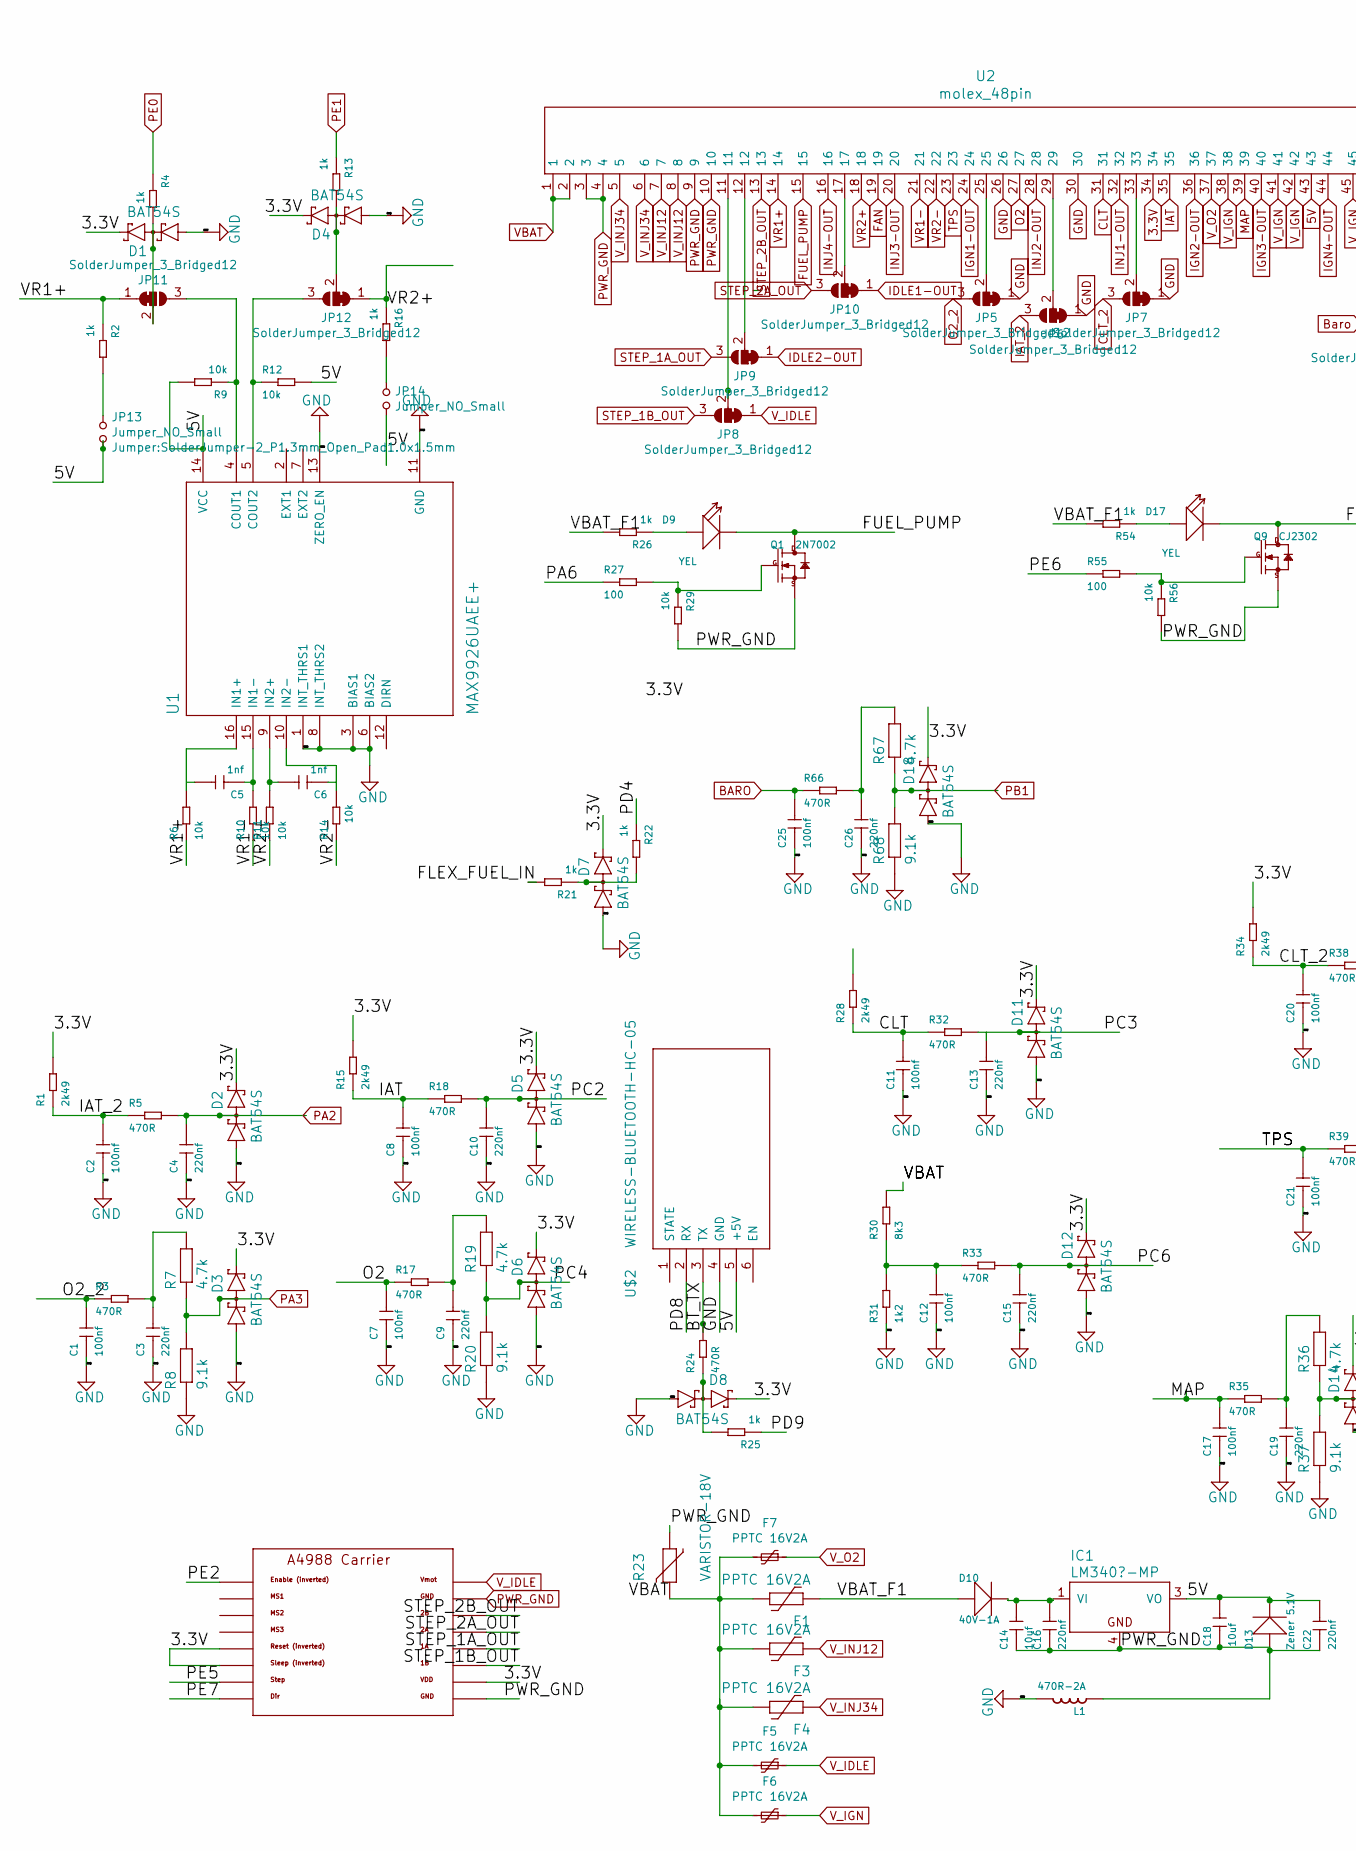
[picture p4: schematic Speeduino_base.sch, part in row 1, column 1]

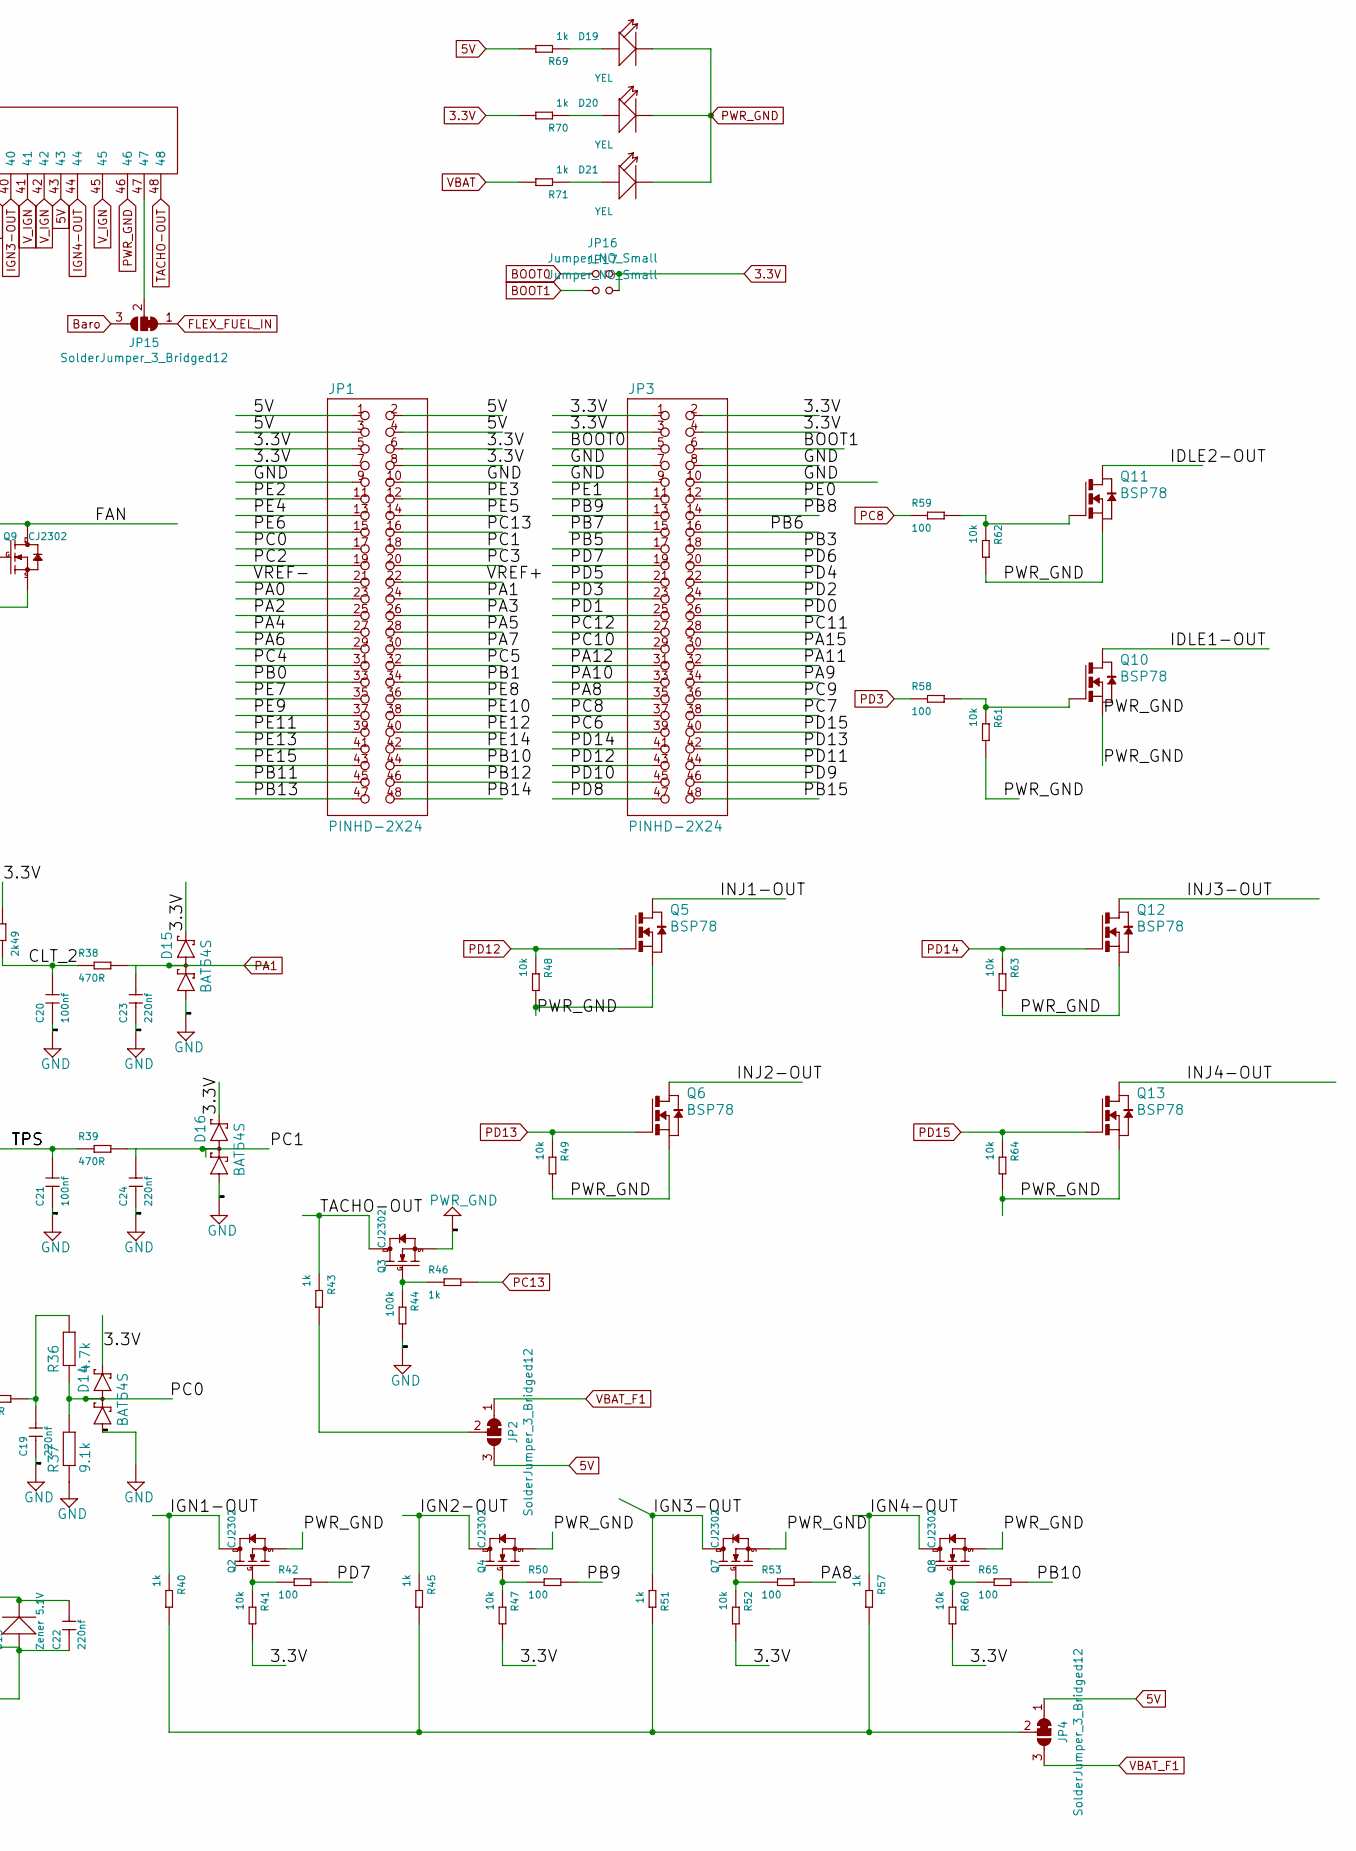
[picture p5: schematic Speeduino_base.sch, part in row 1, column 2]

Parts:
C1, C2, C7, C8, C11, C12, C17, C20, C21, C25: 100nf; C0603
C3, C4, C9, C10, C13, C15, C16, C19, C22, C23, C24, C26: 220nf; C0603
C5, C6: 1nf; C0603
C14, C18: 10uf; C1206
D1, D2, D3, D4, D5, D6, D7, D8, D11, D12, D14, D15, D16, D18: BAT54S; SOT23
D9, D17, D19, D20, D21: YEL; LED-0603
D10: 40V-1A; DO-214AC
D13: Zener 5.1V; LED-1206
F1, F3, F4: PPTC 16V2A; 1812L
F5, F6, F7: PPTC 16V2A; Fuse_1812_4532Metric
IC1: LM340?-MP; SOT223
JP1, JP3: PINHD-2X24; 2X24
JP2, JP4, JP5, JP6, JP7, JP8, JP9, JP10, JP11, JP12, JP15: SolderJumper_3_Bridged12; SolderJumper-3_P1.3mm_Bridged12_Pad1.0x1.5mm
JP13, JP14: Jumper_NO_Small; SolderJumper-2_P1.3mm_Open_Pad1.0x1.5mm
JP16, JP17: Jumper_NO_Small; PinHeader_1x02_P2.54mm_Vertical
L1: 470R-2A; L0805
Q1: 2N7002; SOT-23
Q2, Q3, Q4, Q7, Q8, Q9: CJ2302; SOT-23
Q5, Q6, Q10, Q11, Q12, Q13: BSP78; SOT223
R1, R15, R28, R34: 2k49; R0603
R2, R4, R13, R16, R21, R22, R25, R26, R40, R43, R45, R46, R51, R54, R57, R69, R70, R71: 1k; R0603
R3, R5, R17, R18, R24, R32, R33, R35, R38, R39, R66: 470R; R0603
R6, R9, R10, R11, R12, R14, R29, R41, R47, R48, R49, R52, R56, R60, R61, R62, R63, R64: 10k; R0603
R7, R19, R36, R67: 4.7k; R0603
R8, R20, R37, R68: 9.1k; R0603
R23: VARISTOR-18V; R-7,5
R27, R42, R50, R53, R55, R58, R59, R65: 100; R0603
R30: 8k3; R0603
R31: 1k2; R0603
R44: 100k; R0603
U1: MAX9926UAEE+; 21-0055H_16
U2: molex_48pin; Molex_48
U$1: A4988BREAKOUT
U$2: WIRELESS-BLUETOOTH-HC-05

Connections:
3.3V: D1.2 (C2), D2.2 (C2), D3.2 (C2), D4.2 (C2), D5.2 (C2), D6.2 (C2), D7.2 (C2), D8.2 (C2), D11.2 (C2), D12.2 (C2), D14.2 (C2), D15.2 (C2), D16.2 (C2), D18.2 (C2), JP1.5, JP1.6, JP1.7, JP1.8, JP3.1, JP3.2, JP3.3, JP3.4, JP16.2, JP17.2, R1.2, R15.2, R34.2, R41.2, R47.2, R52.2, R60.2, R70.2, U2.34, U$1.RST, U$1.SLP (SLEEP), U$1.VDD; also elsewhere on the board
5V: C18.2, C22.2, D13.-, IC1.3 (VO), JP1.1, JP1.2, JP1.3, JP1.4, JP2.3 (B), JP4.1 (A), JP13.2, JP14.2, R9.2, R12.2, R69.2, U1.14 (VCC), U2.43, U$2.5 (+5V)
/BT_TX: R24.2, U$2.3 (TX)
/PA0: JP1.23
/PA4: JP1.27
/PA5: JP1.28
/PA6: JP1.29, R27.1
/PA7: JP1.30
/PA8: JP3.35, R53.2
/PA11: JP3.32
/PA12: JP3.31
/PA15: JP3.30
/PB0: JP1.33
/PB3: JP3.18
/PB5: JP3.17
/PB6: JP3.16
/PB7: JP3.15
/PB8: JP3.14
/PB9: JP3.13, R50.2
/PB10: JP1.44, R65.2
/PB11: JP1.45
/PB12: JP1.46
/PB13: JP1.47
/PB14: JP1.48
/PB15: JP3.48
/PC0: D14.3 (C1A2), JP1.17, R36.1, R37.2
/PC1: D16.3 (C1A2), JP1.18, R39.2
/PC2: C10.2, D5.3 (C1A2), JP1.19, R18.2
/PC3: D11.3 (C1A2), JP1.20, R32.2
/PC4: D6.3 (C1A2), JP1.31, R19.1, R20.2
/PC5: JP1.32
/PC6: C15.2, D12.3 (C1A2), JP3.39, R33.2
/PC7: JP3.38
/PC9: JP3.36
/PC10: JP3.29
/PC11: JP3.28
/PC12: JP3.27
/PD0: JP3.26
/PD1: JP3.25
/PD2: JP3.24
/PD4: JP3.22, R22.1
/PD5: JP3.21
/PD6: JP3.20
/PD7: JP3.19, R42.2
/PD8: JP3.47, U$2.2 (RX)
/PD9: JP3.46, R25.1
/PD10: JP3.45
/PD11: JP3.44
/PE2: JP1.11, U$1.EN
/PE3: JP1.12
/PE4: JP1.13
/PE5: JP1.14, U$1.STEP
/PE6: JP1.15, R55.1
/PE7: JP1.35, U$1.DIR
/PE8: JP1.36
/PE9: JP1.37
/PE10: JP1.38
/PE11: JP1.39
/PE12: JP1.40
/PE13: JP1.41
/PE14: JP1.42
/PE15: JP1.43
/VREF+: JP1.22
/VREF-: JP1.21
BARO: C25.2, R66.1
BOOT0: JP3.5, JP16.1
BOOT1: JP3.6, JP17.1
Baro: JP15.3 (B)
CLT: C11.2, R28.1, R32.1, U2.31
CLT_2: C20.2, JP7.3 (B), R34.1, R38.1
FAN: D17.-, Q9.3 (D), U2.19
FLEX_FUEL_IN: JP15.1 (A), R21.2
FUEL_PUMP: D9.-, Q1.3 (D), U2.15
GND: C1.1, C2.1, C3.1, C4.1, C7.1, C8.1, C9.1, C10.1, C11.1, C12.1, C13.1, C15.1, C17.1, C19.1, C20.1, C21.1, C23.1, C24.1, C25.1, C26.1, D1.1 (A1), D2.1 (A1), D3.1 (A1), D4.1 (A1), D5.1 (A1), D6.1 (A1), D7.1 (A1), D8.1 (A1), D11.1 (A1), D12.1 (A1), D14.1 (A1), D15.1 (A1), D16.1 (A1), D18.1 (A1), JP1.9, JP1.10, JP3.7, JP3.8, JP3.9, JP3.10, JP5.1 (A), JP6.1 (A), JP7.1 (A), L1.2, Q3.2 (S), R8.1, R20.1, R31.1, R37.1, R44.2, R68.1, U1.1 (INT_THRS1), U1.3 (BIAS1), U1.6 (BIAS2), U1.8 (INT_THRS2), U1.11 (GND), U1.13 (ZERO_EN), U2.26, U2.30, U$2.4 (GND); also elsewhere on the board
IAT: C8.2, R15.1, R18.1, U2.35
IAT_2: C2.2, JP6.3 (B), R1.1, R5.1
IDLE1-OUT: JP10.1 (A), Q10.2 (D), Q10.4 (D)
IDLE2-OUT: JP9.1 (A), Q11.2 (D), Q11.4 (D)
IGN1-OUT: Q2.3 (D), R40.1, U2.24
IGN2-OUT: Q4.3 (D), R45.1, U2.36
IGN3-OUT: Q7.3 (D), R51.1, U2.40
IGN4-OUT: Q8.3 (D), R57.1, U2.44
INJ1-OUT: Q5.2 (D), Q5.4 (D), U2.32
INJ2-OUT: Q6.2 (D), Q6.4 (D), U2.28
INJ3-OUT: Q12.2 (D), Q12.4 (D), U2.20
INJ4-OUT: Q13.2 (D), Q13.4 (D), U2.16
MAP: C17.2, R35.1, U2.39
unnamed: C3.2, R3.2, R7.2
unnamed: C5.1, R10.2, U1.15 (IN1-)
unnamed: C6.2, R11.2, U1.9 (IN2+)
unnamed: C9.2, R17.2, R19.2
unnamed: C12.2, R30.1, R31.2, R33.1
unnamed: C14.2, C16.2, D10.2 (-), IC1.1 (VI)
unnamed: C19.2, R35.2, R36.2
unnamed: C26.2, R66.2, R67.2
unnamed: D1.3 (C1A2), JP11.2 (C), R4.2
unnamed: D4.3 (C1A2), JP12.2 (C), R13.2
unnamed: D7.3 (C1A2), R21.1, R22.2
unnamed: D8.3 (C1A2), R24.1, R25.2
unnamed: D9.+, R26.1
unnamed: D17.+, R54.1
unnamed: D19.+, R69.1
unnamed: D20.+, R70.1
unnamed: D21.+, R71.1
unnamed: JP2.2 (C), R43.2
unnamed: JP4.2 (C), R40.2, R45.2, R51.2, R57.2
unnamed: JP5.2 (C), U2.25
unnamed: JP6.2 (C), U2.29
unnamed: JP7.2 (C), U2.33
unnamed: JP8.2 (C), U2.11
unnamed: JP9.2 (C), U2.12
unnamed: JP10.2 (C), U2.17
unnamed: JP11.3 (B), R9.1, U1.4 (COUT1)
unnamed: JP12.3 (B), R12.1, U1.5 (COUT2)
unnamed: JP13.1, R2.2
unnamed: JP14.1, R16.2
unnamed: JP15.2 (C), U2.47
unnamed: Q1.1 (G), R27.2, R29.1
unnamed: Q2.1 (G), R41.1, R42.1
unnamed: Q3.1 (G), R44.1, R46.1
unnamed: Q4.1 (G), R47.1, R50.1
unnamed: Q7.1 (G), R52.1, R53.1
unnamed: Q8.1 (G), R60.1, R65.1
unnamed: Q9.1 (G), R55.2, R56.1
unnamed: Q10.1 (G), R58.2, R61.1
unnamed: Q11.1 (G), R59.2, R62.1
unnamed: R6.2, U1.16 (IN1+)
unnamed: R14.2, U1.10 (IN2-)
O2: C7.2, R17.1, U2.27
O2_2: C1.2, JP5.3 (B), R3.1
PA1: D15.3 (C1A2), JP1.24, R38.2
PA2: C4.2, D2.3 (C1A2), JP1.25, R5.2
PA3: D3.3 (C1A2), JP1.26, R7.1, R8.2
PA9: JP3.34; also elsewhere on the board
PA10: JP3.33; also elsewhere on the board
PB1: D18.3 (C1A2), JP1.34, R67.1, R68.2
PC8: JP3.37, R59.1
PC13: JP1.16, R46.2
PD3: JP3.23, R58.1
PD12: JP3.43, Q5.1 (G), R48.1
PD13: JP3.42, Q6.1 (G), R49.1
PD14: JP3.41, Q12.1 (G), R63.1
PD15: JP3.40, Q13.1 (G), R64.1
PE0: JP3.12, R4.1
PE1: JP3.11, R13.1
PWR_GND: C14.1, C16.1, C18.1, C22.1, D13.+, D19.-, D20.-, D21.-, IC1.4 (GND), L1.1, Q1.2 (S), Q2.2 (S), Q4.2 (S), Q5.3 (S), Q6.3 (S), Q7.2 (S), Q8.2 (S), Q9.2 (S), Q10.3 (S), Q11.3 (S), Q12.3 (S), Q13.3 (S), R23.1, R29.2, R48.2, R49.2, R56.2, R61.2, R62.2, R63.2, R64.2, U2.3, U2.4, U2.9, U2.10, U2.46, U$1.GND (GND@0), U$1.GND@0 (GND@1); also elsewhere on the board
STEP_1A_OUT: JP9.3 (B), U$1.1A
STEP_1B_OUT: JP8.3 (B), U$1.1B
STEP_2A_OUT: JP10.3 (B), U$1.2A
STEP_2B_OUT: U2.13, U$1.2B
TACHO-OUT: Q3.3 (D), R43.1, U2.48
TPS: C21.2, R39.1, U2.23
VBAT: F1.1, F3.1, F4.1, F5.2, F6.2, F7.2, R23.2, R30.2, R71.2, U2.1, U2.2
VBAT_F1: D10.1 (+), F1.2, JP2.1 (A), JP4.3 (B), R26.2, R54.2
VR1+: JP11.1 (A), R2.1, R6.1, U2.14
VR1-: R10.1, U2.21
VR2+: JP12.1 (A), R11.1, R16.1, U2.18
VR2-: R14.1, U2.22
V_IDLE: F5.1, JP8.1 (A), U$1.VMOT
V_IGN: F6.1, U2.38, U2.41, U2.42, U2.45
V_INJ12: F3.2, U2.7, U2.8
V_INJ34: F4.2, U2.5, U2.6
V_O2: F7.1, U2.37

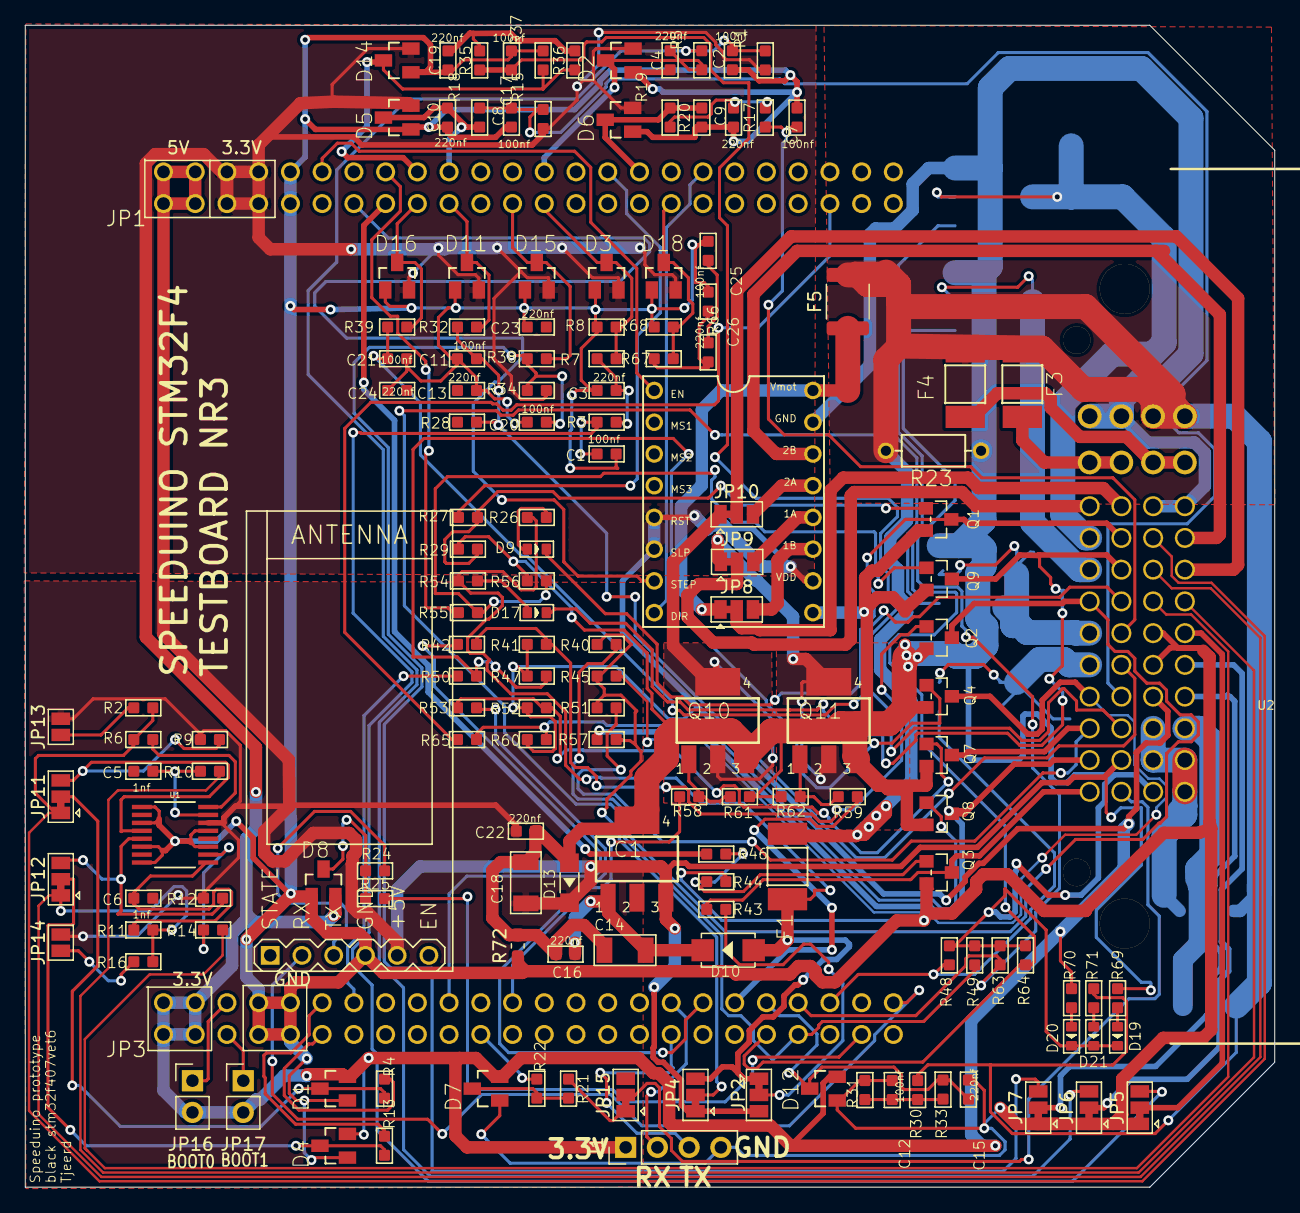
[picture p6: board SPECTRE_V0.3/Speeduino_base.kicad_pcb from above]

Board: 2 copper layers, 100.0 x 93.0 mm, 161 parts (0 on the bottom side), 119 nets.

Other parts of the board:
J1: Conn_01x04_Male; PinHeader_1x04_P2.54mm_Vertical
R72: 0R0; R_0603_1608Metric_Pad1.05x0.95mm_HandSolder

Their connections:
3.3V: J1.1; also elsewhere on the board
GND: J1.4, R72.1; also elsewhere on the board
PA9: J1.3; also elsewhere on the board
PA10: J1.2; also elsewhere on the board
PWR_GND: R72.2; also elsewhere on the board

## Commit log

2020-02-27 Cleaned up V0.4 Bug fixes in board V0.4 Changed readme to add more to be tested functions
    [Speeduino_base-B_Mask.gbs, Speeduino_base-B_Paste.gbp, Speeduino_base-B_SilkS.gbo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]
2020-03-22 Lots of changes, started new PCB with 8 inj channels.
    [Speeduino_base.kicad_pcb, Speeduino_base.sch]
2020-03-22 All tracks routed: TODO: Copper GND, Copper Cooling transistors, Check to220 5v direction
    [Speeduino_base.kicad_pcb]
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2020-03-23 Add zener for safety on 3.3v. All bat54S diodes dump current on 3.3V line when driven above 3.6V therefor the 3.3V needed protection
    [Speeduino_base.kicad_pcb, Speeduino_base.sch]
2020-03-25 add canbus driver add 3d models to components for 3d render.
    [5007620481.stp, Speeduino_base.kicad_pcb, Speeduino_base.sch]
2020-03-26 rs232 header NRF
    Added rs232 driver and Added NRF header to use SPI .
    TODO:
    - finish rs232 to 48 pin connector
    - route BME280
    [Speeduino_base.kicad_pcb, Speeduino_base.sch]
2020-03-28 rs232 + BME280 finished
    Added rs232 to connector
    Finished BME280 connection and routing
    [Speeduino_base.kicad_pcb, Speeduino_base.sch]
2020-03-28 Added board v0.5
    Added new board V0.5 also generetd gerbers for V0.4
    [5007620481.stp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]
2020-03-28 update silkscreen
    Updated silkscreen V0.4. Start switchable flyback diode in V0.5 for PWM control of injectors
    [Speeduino_base-B_Mask.gbs, Speeduino_base-B_Paste.gbp, Speeduino_base-B_SilkS.gbo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]
2020-03-28 Routing V0.5
    Started routing board V0.5
    [Speeduino_base.kicad_pcb, Speeduino_base.sch]
2020-03-29 WPM peak&hold low-z injector driver
    Add a PWM peak and hold injector driver simulation in LTspice. Not perfect yet but good learning experience.
    [Speeduino_base.sch]
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2020-03-31 peak & hold injector driver update
    Updates to Low-z PWM peak & hold injector driver schematic.
    Updates simulation low-z driver.
    [Speeduino_base.kicad_pcb, Speeduino_base.sch]
2020-03-31 Updates on routing V0.5 board
    Switched some pins also updated the board routing a bit. not done yet.
    [Speeduino_base.kicad_pcb, Speeduino_base.sch]
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2020-04-04 Routing and testing
    Test Some more functions of the V0.3 also routed the V0.5 furhter
    [Speeduino_base.kicad_pcb]
2020-04-05 Somem ore routing V0.5
    Routing board V0.5
    [Speeduino_base.kicad_pcb, Speeduino_base.sch]
2020-04-05 3.3V power protection
    Extra protection for the 3.3volt supply. TL431 is used for this.
    [Speeduino_base.kicad_pcb, Speeduino_base.sch]
2020-04-05 routing V0.5
    Some more routing V0.5
    [Speeduino_base.kicad_pcb]
2020-04-05 V0.5 fully routed
    Routed the whole SPECTRE V0.5 board
    [Speeduino_base.kicad_pcb, Speeduino_base.sch]
2020-04-05 Fixed some DRC errors
    [Speeduino_base-B_Mask.gbs, Speeduino_base-B_Paste.gbp, Speeduino_base-B_SilkS.gbo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]
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2020-04-08 Cleanedup acute angles
    Cleaned up a lot of the accute angles as suggested by JHolland on the forum
    [Speeduino_base-B_Mask.gbs, Speeduino_base-B_Paste.gbp, Speeduino_base-B_SilkS.gbo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]
2020-04-08 updated bluetooth
    Now bluetooth is not on second serial anymore. Bluetooth is on Serial1
    [Speeduino_base-B_Mask.gbs, Speeduino_base-B_Paste.gbp, Speeduino_base-B_SilkS.gbo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]
2020-04-10 Started on peak & hold schematic
    [PeakHoldPWMDriver.kicad_pcb, PeakHoldPWMDriver.sch]
2020-05-07 boost pin change
    update pin def boost pin
    [Speeduino_base.kicad_pcb, Speeduino_base.sch]
2020-07-02 Stared implementing peak and hold driver. Also started in V0.6 of my board where the peak and hold driver is included
    [5007620481.stp, PeakHoldPWMDriver.kicad_pcb, PeakHoldPWMDriver.sch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]
2020-07-03 Cleaned and updated the SPECTRE V0.5 Created separate Peak and Hold board.
    [PeakHoldPWMDriver.kicad_pcb, PeakHoldPWMDriver_annotate.sch, Speeduino_base.kicad_pcb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]
2020-07-03 create gerberbers
    created gerbers for the order. Peak and Hold and the SPECTRE V0.5
    [PeakHoldPWMDriver-B_Cu.gbr, PeakHoldPWMDriver-B_Mask.gbr, PeakHoldPWMDriver-B_Paste.gbr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]
2020-07-13 Removed peak&hold driver from this repo. Update resistor values in schematic to values that work. Cleaned up resistor naming.
    [PeakHoldPWMDriver-B_Cu.gbr, PeakHoldPWMDriver-B_Mask.gbr, PeakHoldPWMDriver-B_Paste.gbr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]
2020-07-13 Removed V0.6 because there is not going to be a V0.6 anytime soon.
    [5007620481.stp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]
2020-07-19 clean-up board V0.5 started on board V0.5.1
    [5007620481.stp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]
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2020-08-01 Add V0.5.1
    Added V0.5.2
    - Proto area
    - 6ign outputs
    - mosfet drivers for ign outputs
    [5007620481.stp, Speeduino_base.kicad_pcb, Speeduino_base.sch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]
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2020-11-11 Start on V0.5.3
    Started on V0.5.3 tfor some inprovements
    - Seriie resistance for ignition drivers
    - Boot0 to external connector for easy flashing when ECU is hard to reach
    - Simplify the and improve robustness of VR/HALL sensor stuff
    [5007620481.stp, Speeduino_base.kicad_pcb, Speeduino_base.sch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]
2020-12-30 Now with correct file/lib locations for the 48pin molex
    [Speeduino_base.sch]
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2020-12-30 update molex 48 pin to correct location
    [Speeduino_base.kicad_pcb, Speeduino_base.sch]
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2021-01-18 Complete rework on PCB
    [Speeduino_base.kicad_pcb, Speeduino_base.sch]
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2021-02-08 Update V0.5.3 Update JLCpcb part numbers in schematic Updated board layout. Added bom for JLCPCB SMT service Added location file for JLCPCB SMT service
    [BOM.csv, BOM.ods, BOM_Placement.ods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]
2021-03-05 General cleanup, update Readme and add BOM list
    [BOM.ods, BOM_Placement.ods, BOM_Placement_JLCPCB.csv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]
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
